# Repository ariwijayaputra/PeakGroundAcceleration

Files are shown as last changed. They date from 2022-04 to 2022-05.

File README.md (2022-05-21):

# PeakGroundAcceleration

# Schematic
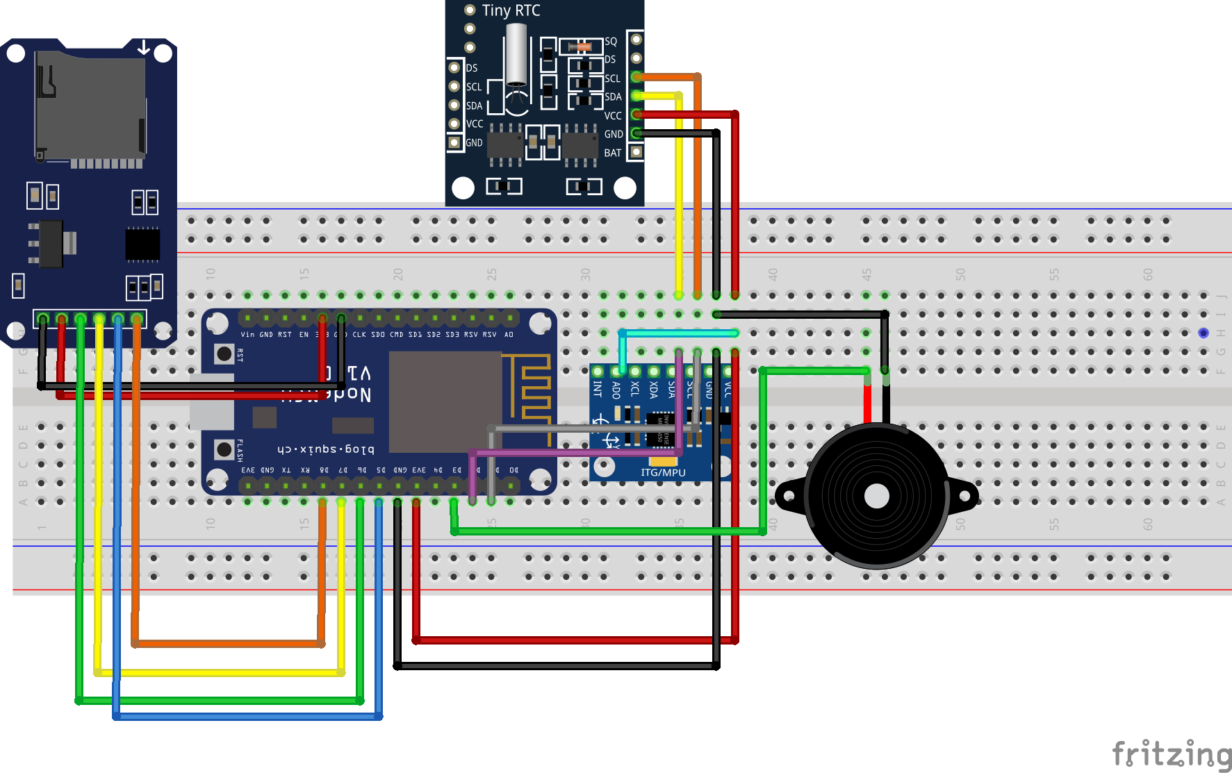
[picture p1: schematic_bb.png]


# Setup Web
1. download code dalam zip
2. extract ke folder htdocs xampp
3. buka phpmyadmin, buat database dengan nama pga
4. import pga.sql ke database yang baru dibuat
5. buka http://localhost:8080/PeakGroundAcceleration-main/mqtt%20esp8266%20accel/web/login.php

# Setup alat
1. buka PeakGroundAcceleration-main\Arduino\PeakGroundAccelESP8266
2. download library yang dibutuhkan
   a. MPU6050 v0.5.0 by Electronic Cats,
   b. PubSubClient v2.8.0 by Nick O'Leary,
   c. CircularBuffer by AgileWare,
   d. Rtc by Makuna Michael C. Miller,
   e. SD by arduino
3. setup esp8266 for arduino ide (jika belum) -> https://randomnerdtutorials.com/how-to-install-esp8266-board-arduino-ide/
4. pilih board NodeMCU 1.0(ESP-12e Module), setting port.
5. ubah SSID dan Password wifi pada coding.
6. compile & upload

# Download
1. download csv melalui tombol download pada website
2. buka https://docs.google.com/spreadsheets/u/0/
3. klik blank
4. klik file>import>upload, pilih file yang telah di download atau drag and drop, import data
5. klik file>download>(pilih format)

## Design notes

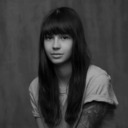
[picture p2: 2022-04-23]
mqtt esp8266 accel/web/dist/img/user4-128x128.jpg

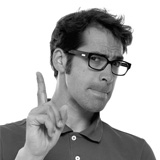
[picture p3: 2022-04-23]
mqtt esp8266 accel/web/dist/img/user2-160x160.jpg

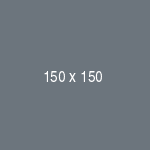
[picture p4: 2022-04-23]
mqtt esp8266 accel/web/dist/img/default-150x150.png

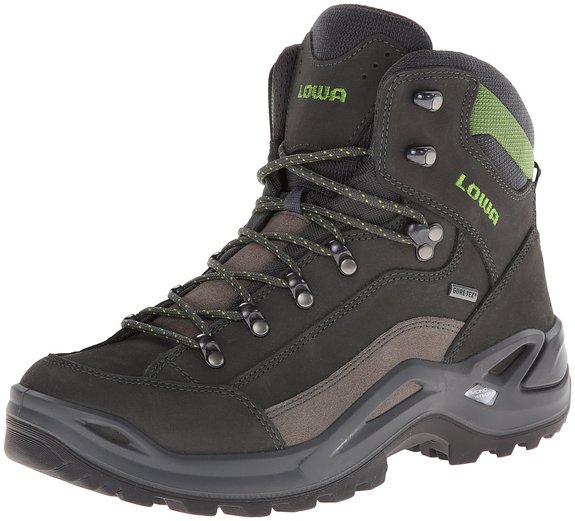
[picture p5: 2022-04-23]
mqtt esp8266 accel/web/dist/img/prod-1.jpg

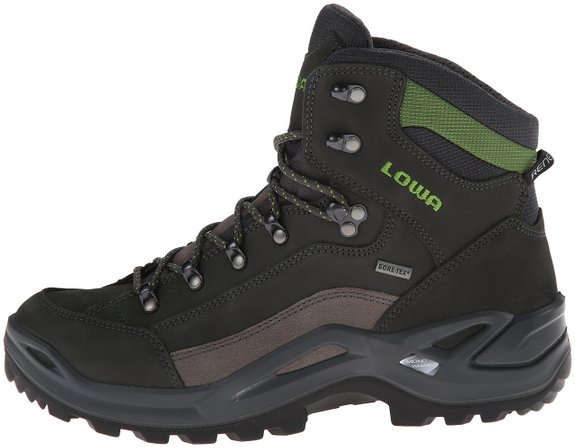
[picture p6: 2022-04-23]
mqtt esp8266 accel/web/dist/img/prod-2.jpg

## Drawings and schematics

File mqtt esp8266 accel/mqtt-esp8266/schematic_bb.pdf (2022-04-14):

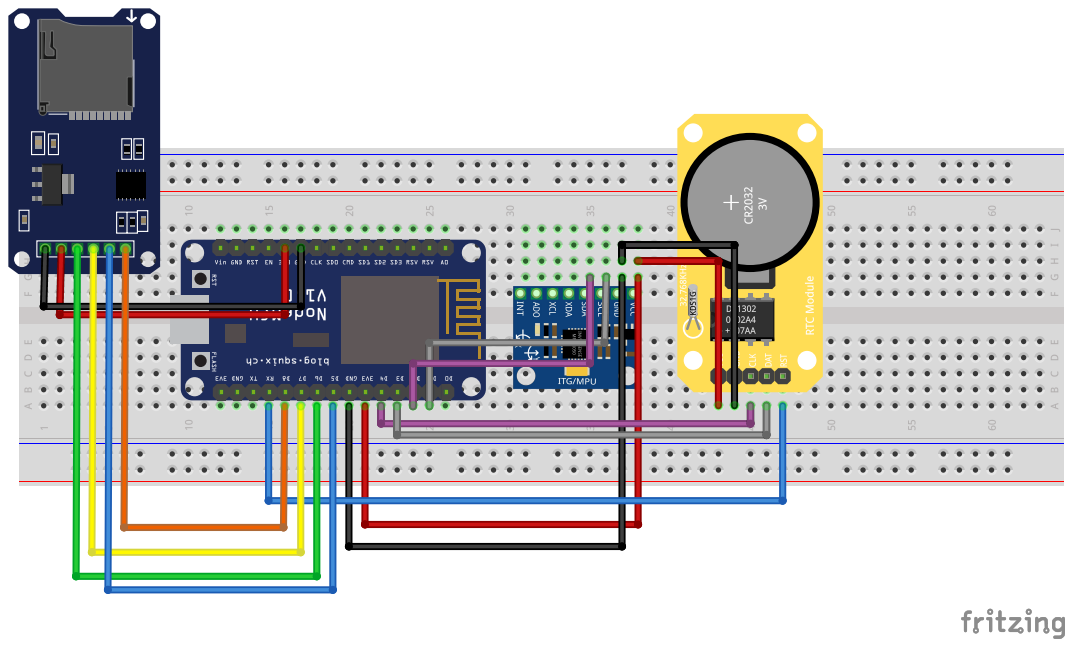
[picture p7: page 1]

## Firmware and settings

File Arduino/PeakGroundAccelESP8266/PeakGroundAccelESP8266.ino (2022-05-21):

#include <Arduino.h>
#include <elapsedMillis.h>
#include <ESP8266WiFi.h>
#include <PubSubClient.h>
#include <MPU6050.h>
#include <CircularBuffer.h>
#include <ThreeWire.h>  
#include <RtcDS1307.h>
#include "SPI.h"
#include "SD.h"

#include "I2Cdev.h"


#if I2CDEV_IMPLEMENTATION == I2CDEV_ARDUINO_WIRE
    #include "Wire.h"
#endif

// variabel WiFi credential
const char* ssid     = "";
const char* password = "";

// variabel MQTT Broker/server
const char *mqtt_broker = "maqiatto.com"; //domain atau ip server mqtt
const char *topic = "peakgroundaccelapp@gmail.com/accel";
const char *mqtt_username = "peakgroundaccelapp@gmail.com";
const char *mqtt_password = "acceleration";
const int mqtt_port = 1883;

// variable buzzer
const int buzzer = D3;
elapsedMillis buzzerDelay;
boolean buzzerState = LOW;

// variable accel MPU6050
MPU6050 accel(0x69);
int16_t ax, ay, az; //raw data
float gX, gY, gZ = 0.000000; // acceleration in g
CircularBuffer<int,5> bufferX; // array dalam proses reduce noise x
CircularBuffer<int,5> bufferY; // array dalam proses reduce noise y
CircularBuffer<int,5> bufferZ; // array dalam proses reduce noise z
long AccX,AccY,AccZ = 0; //variabel menyimpan raw accel yang telah di reduce noise
float mX, mY, mZ = 0.000000; // variabel menyimpan acceleration dalam cm/s^2
float pga; //variabel menyimpan pga
float v; //variable menyimapn velocity
String damage;
String shake;
String intensity;

// Variabel sdcard
const int chipSelect = D8; //pin sdcard
File dataFile = SD.open("log.txt", FILE_WRITE);

// variable RTC DS1302
RtcDS1307<TwoWire> Rtc(Wire);
#define countof(a) (sizeof(a) / sizeof(a[0]))

// elasedMillis sebagai timer untuk publish data
elapsedMillis publishTimer;
elapsedMillis accelTimer;

// buat client untuk interaksi dengan wifi dan broker
WiFiClient espClient;
PubSubClient client(espClient);

// --- start of connectWifi() ---
// fungsi untuk connect ke wifi
void connectWifi(){
  // mulai koneksi
  WiFi.begin(ssid,password);
  // tunggu sampai status connected
  while (WiFi.status() != WL_CONNECTED) 
  {
     delay(500);
     Serial.print("*");
  }
  Serial.println();
  Serial.println("-- WiFi Connected --");
}
// --- end of connectWifi() ---


// --- start of callback() ---
// fungsi untuk menerima data dari server mqtt.
// dijalankan otomatis setiap menerima data pada topic.
void callback(char *topic, byte *payload, unsigned int length) {
  Serial.print("Message arrived in topic: ");
  Serial.println(topic);
  Serial.print("Message:");
  for (int i = 0; i < length; i++) {
    Serial.print((char) payload[i]);
  }
  Serial.println("-----------------------");
}
// --- end of callback() ---


// --- start of connectBroker() ---
// fungsi untuk connect ke mqtt server/broker
void connectBroker(){
  client.setServer(mqtt_broker, mqtt_port);
  client.setCallback(callback);
  // ulang koneksi hingga status client connected
  while (!client.connected()) {
    String client_id = "esp8266-client-";
    client_id += String(WiFi.macAddress());
    Serial.printf("The client %s is connecting to mqtt broker\n", client_id.c_str());
    if (client.connect(client_id.c_str(), mqtt_username, mqtt_password)) {
      Serial.println("MQTT broker/server connected");
    } else {
      Serial.print("failed with state ");
      Serial.print(client.state());
      delay(2000);
    }
  }
  Serial.println();
  // subscribe untuk menerima data dari topic mqtt
  client.subscribe(topic);
  if (client.subscribe(topic))
  {
    Serial.println("subscribe success");
  }
}
// --- end of connectBroker() ---


// --- start of printDateTime ---
// format data rtc dan print ke serial monitor
void printDateTime(const RtcDateTime& dt)
{
    char datestring[20];

    snprintf_P(datestring, 
            countof(datestring),
            PSTR("%02u/%02u/%04u %02u:%02u:%02u"),
            dt.Day(),
            dt.Month(),
            dt.Year(),
            dt.Hour(),
            dt.Minute(),
            dt.Second() );
    Serial.print(datestring);
}
// --- end of printDateTime ---


// --- start of setupBuzzer() ---
void setupBuzzer(){
  pinMode(buzzer, OUTPUT);
}
// --- end of setupBuzzer() ---


// --- start of setupSD() ---
void setupSD(){
  Serial.println("Initializing SD card...");
  // make sure that the default chip select pin is set to
  // output, even if you don't use it:
  pinMode(SS, OUTPUT);
  
  // cek apakah ada kartu sd
  if (!SD.begin(chipSelect)) {
    Serial.println("Card failed or not present, check sd card and module connection");
    Serial.println("Waiting for card connection....");
    while (!SD.begin(chipSelect))
    {
      delay(500);
    }
  }
  Serial.println("card initialized.");
  
  // open the file. note that only one file can be open at a time,
  // so you have to close this one before opening another.
  File dataFile = SD.open("log.txt", FILE_WRITE);
}
// --- end  of setupSD() ---


// --- start of setupRTC() ---
// fungsi untuk konfigurasi awal dan menyalakan RTC
void setupRTC(){
  Serial.print("compiled: ");
    Serial.print(__DATE__);
    Serial.println(__TIME__);

    Rtc.Begin();

    RtcDateTime compiled = RtcDateTime(__DATE__, __TIME__);
    printDateTime(compiled);
    Serial.println();

    if (!Rtc.IsDateTimeValid()) 
    {
        // Common Causes:
        //    1) first time you ran and the device wasn't running yet
        //    2) the battery on the device is low or even missing

        Serial.println("RTC lost confidence in the DateTime!");
        Rtc.SetDateTime(compiled);
    }

    if (!Rtc.GetIsRunning())
    {
        Serial.println("RTC was not actively running, starting now");
        Rtc.SetIsRunning(true);
    }

    RtcDateTime now = Rtc.GetDateTime();
    if (now < compiled) 
    {
        Serial.println("RTC is older than compile time!  (Updating DateTime)");
        Rtc.SetDateTime(compiled);
    }
    else if (now > compiled) 
    {
        Serial.println("RTC is newer than compile time. (this is expected)");
    }
    else if (now == compiled) 
    {
        Serial.println("RTC is the same as compile time! (not expected but all is fine)");
    }
}
// --- end of setupRTC() ---



void getRTCData(RtcDateTime now){
  
  printDateTime(now);
  Serial.println();

  if (!now.IsValid())
  {
      // Common Causes:
      //    1) the battery on the device is low or even missing and the power line was disconnected
      Serial.println("RTC lost confidence in the DateTime!");
  }
}

// --- start of setupMPU6050() ---
// fungsi untuk konfigurasi awal dan menyalakan sensor mpu 6050
void setupMPU6050(){
  // join I2C bus (I2Cdev library doesn't do this automatically)
  #if I2CDEV_IMPLEMENTATION == I2CDEV_ARDUINO_WIRE
      Wire.begin();
  #elif I2CDEV_IMPLEMENTATION == I2CDEV_BUILTIN_FASTWIRE
      Fastwire::setup(400, true);
  #endif
  // inisiasi dan menyalakan MPU6050. diatur melalui pin D3
  Serial.println("Initializing I2C devices...");
  //pinMode(D3,OUTPUT);
  //digitalWrite(D3, HIGH);
  delay(1000);
  accel.initialize();
  delay(1000);
  // cek koneksi
  Serial.println("Testing device connections...");
  Serial.println(accel.testConnection() ? "MPU6050 connection successful" : "MPU6050 connection failed");
}


// --- start of convert() ---
// fungsi untuk convert MPU 6050 raw data to readable data
void convert(int x, int y, int z){
  // berdasarkan datasheet mpu6050, 16384 lsb = 1g
  gX = float(x) / 16384.000000;
  gY = float(y) / 16384.000000;
  gZ = float(z) / 16384.000000;

  // convert g -> m/s^2. 1g = 980cm/s^2
  mX = gX * 980;
  mY = gY * 980;
  mZ = gZ * 980;

  // pga (g) = sqrt(gx^2 + gY^2). pga dihitung dengan pitagoras
  // untuk mengkombinasikan hasil akselerasi sumbu x dan y
  pga = sqrt((gX*gX)+(gY*gY));
  v = pga*980; 
  if(pga < 0.000464){
        shake = "Not Felt";
        damage = "None";
        intensity= "I";
      } 
      else if(pga > 0.000464 && pga<=0.00297){
        shake = "Weak";
        damage = "None";
        intensity= "II -III";
      }
      else if(pga > 0.00297 && pga<=0.0276){
        shake = "Light";
        damage = "None";
        intensity= "IV";
        
      }
      else if(pga > 0.0276 && pga<=0.115){
        shake = "Moderate";
        damage = "Very Light";
        intensity= "V";
      }
      else if(pga > 0.115 && pga<=0.215){
        shake = "Strong";
        damage = "Light";
        intensity= "VI";
      }
      else if(pga > 0.215 && pga<=0.401){
        shake = "Very Strong";
        damage = "Moderate";
        intensity= "VII";
      }
      else if(pga > 0.401 && pga<=0.747){
        shake = "Severe";
        damage = "Moderate to Heavy";
        intensity= "VIII";
      }
      else if(pga > 0.747 && pga<=1.39){
        shake = "Violent";
        damage = "Heavy";
        intensity= "IX";
      }
      else if(pga > 1.39){
        shake = "Extreme";
        damage = "Very Heavy";
        intensity= "X+";
      }
}
// --- end of convert() ---


//--- start of getReducedNoiseAccel() ---
// fungsi untuk mengurangi noice yang didapat dari sensor
void getReducedNoiseAccel(){
  
  if(accelTimer>200){
    accel.getAcceleration(&ax, &ay, &az);
    AccX = 0;
    AccY = 0;
    AccZ = 0;
    bufferX.push(ax);
    bufferY.push(ay);
    bufferZ.push(az);
    if(bufferZ.isFull()){
      for (size_t i = 0; i < 5; i++)
      {
        AccX += bufferX[i];
        AccY += bufferY[i];
        AccZ += bufferZ[i];
      }
      
      AccX = AccX/5;
      AccY = AccY/5;
      AccZ = AccZ/5;
      convert(AccX, AccY, AccZ);
    }
    accelTimer = 0;
  }
}
//--- end of getReducedNoiseAccel() ---


// --- start of calibrateAccel ---
// fungsi untuk mengkalibrasi sensor acceleration,
// letakan alat di bidang datar dan stabil selama kalibrasi 
void calibrateAccel(){
  Serial.println("Calibrating... dont move the device");
  delay(5000);
  accel.CalibrateAccel(6);
  accel.CalibrateGyro(6);
  accel.PrintActiveOffsets();
  Serial.println();
  accel.CalibrateAccel(1);
  accel.CalibrateGyro(1);
  accel.PrintActiveOffsets();
  Serial.println();
  accel.CalibrateAccel(1);
  accel.CalibrateGyro(1);
  accel.PrintActiveOffsets();
  Serial.println();
  accel.CalibrateAccel(1);
  accel.CalibrateGyro(1);
  accel.PrintActiveOffsets();
  Serial.println();    
  accel.CalibrateAccel(1);
  accel.CalibrateGyro(1);
  accel.setXAccelOffset(accel.getXAccelOffset());
  accel.setYAccelOffset(accel.getYAccelOffset());
  accel.setZAccelOffset(accel.getZAccelOffset());
  accel.PrintActiveOffsets();
  Serial.println("Calibrating done");
}
// --- end of callibrateAccel() ---


// --- start of monitorData() ---
// mencetak data accelerometer ke serial monitor 9600
// gx | gy | gz | mx | my | mz | pga | v |
void monitorData(){
  Serial.print(gX,6); Serial.print("\t");
  Serial.print(gY,6); Serial.print("\t");
  Serial.print(gZ,6); Serial.print("\t");
  Serial.print(mX,6); Serial.print("\t");
  Serial.print(mY,6); Serial.print("\t");
  Serial.print(mZ,6); Serial.print("\t"); 
  Serial.print(pga,6); Serial.print("\t"); 
  Serial.print(v,6); Serial.print("\t"); 
  Serial.println();
}
// --- end of monitorData() ---


// --- start of publishData() ---
// fungsi untuk memformat data dan
// mengirim data ke mqtt 
void publishData(const RtcDateTime& dt, float pga, float v){
  char publishStr[56];
  sprintf(
    publishStr, "%02u/%02u/%04u %02u:%02u:%02u,%.6f,%.6f,",
    dt.Month(),
    dt.Day(),
    dt.Year(),
    dt.Hour(),
    dt.Minute(),
    dt.Second(),
    pga, 
    v
  
  );
  //Serial.println(publishStr);
  if (!client.publish(topic,publishStr))
  {
    Serial.println("failed publish. Reconnecting");
    connectBroker();
  }
  
  Serial.print(publishStr);
  Serial.print(intensity);
  Serial.print(",");
  Serial.print(shake);
  Serial.print(",");
  Serial.print(damage);
  Serial.println(",");

  if(pga > 0.00297 && pga<=0.0276){
    buzzerDelay = 950;
    digitalWrite(buzzer,HIGH); 
  }
  else if(pga > 0.0276 && pga<=0.115){
    buzzerDelay = 700;
    digitalWrite(buzzer,HIGH);
  }
  else if(pga > 0.115 && pga<=0.215){
    buzzerDelay = 500;
    digitalWrite(buzzer,HIGH);
  }
  else if(pga > 0.215){
    buzzerDelay = 300;
    digitalWrite(buzzer,HIGH);
  }

  File dataFile = SD.open("log.txt", FILE_WRITE);
  if(dataFile){
    dataFile.print(publishStr);
    dataFile.print(intensity);
    dataFile.print(",");
    dataFile.print(shake);
    dataFile.print(",");
    dataFile.print(damage);
    dataFile.println(",");
  }
}
// --- end of publishData() ---



// --- start of setup() ---
// fungsi setup dijalankan pertama kali
void setup() {
  Serial.begin(9600);
  setupRTC();
  setupBuzzer();
  connectWifi();
  connectBroker();
  setupSD();
  // mpu6050 Setup
  setupMPU6050();
  // kalibrasi sensor
  calibrateAccel();
} 
// --- end of setup() ---


// --- start of loop() ---
// fungsi loop dijalankan berulang
void loop() {
  // membuka koneksi mqtt untuk menerima data pada topic
  //client.loop();
  
  //mengambil data dari accelerometer MPU6050
  getReducedNoiseAccel();


  // Publish data setiap detik (1000ms) ke mqtt
  if(publishTimer > 1000){
    //ambil data rtc
    RtcDateTime now = Rtc.GetDateTime();
    getRTCData(now);
    //print data ke serial monitor
    //monitorData();
    //publish data
    publishData(now, pga, v);
    //reset timer
    publishTimer = 0; 
  }
  if(buzzerDelay > 1000){
    digitalWrite(buzzer,LOW);
  }
}
// --- end of loop() ---

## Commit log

2022-04-14 peubahan format pengiriman ke csv
    [schematic.fzz]
2022-04-17 convert main.cpp to ino file arduino IDE
2022-05-21 penggantian RTC dan penambahan buzzer
    [main.cpp]
2022-05-21 add schematic
